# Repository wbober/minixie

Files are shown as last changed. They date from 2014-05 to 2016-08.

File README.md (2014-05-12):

minixie
=======
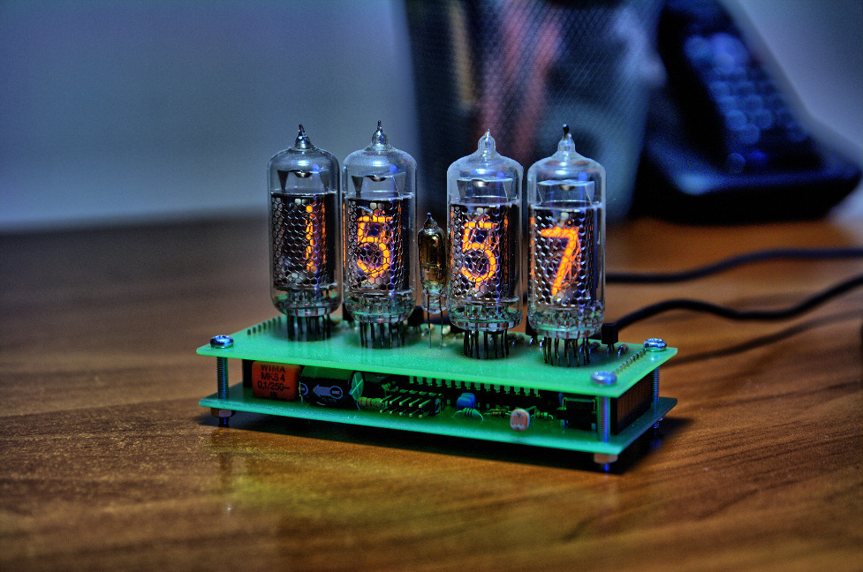
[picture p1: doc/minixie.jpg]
minixie


This project is my take on creating a simple Nixie tube clock. The design uses few
components but packs some nice features.

Features
--------
* a real time clock with super cap backup
* a buzzer
* a light intensity sensor
* an auxiliary connector (UART, IRQ, GPIO, +5V)
* support for an optional DCF77 decoder

Hardware
--------
* only 3 ICs (7805, ATMega8, and 74141 driver)
* single side PCBs
* through-hole components
* designed for LC531 tubes
* small size (46x108mm)
* EagleCAD source for schematics and PCB

Software
--------
* written in C
* tested with AVRStudio/Eclipse

License
-------
Copyright (c) 2012-2014 Wojciech Bober
Licensed under the GNU GPL v2 license

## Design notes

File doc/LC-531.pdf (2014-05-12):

www.tube-tester.com

File created by Dieter Waechter

# Dieter’s Nixie Tube Data Archive

This file is a part of Dieter's Nixie- and display tubes data archive

If you have more datasheets, articles, books, pictures or other information about Nixie tubes or other display devices please let me know. Thank you!

Document in this file | Unitra-Dolam – LC-531 – original datasheet
Display devices in this document | LC-531

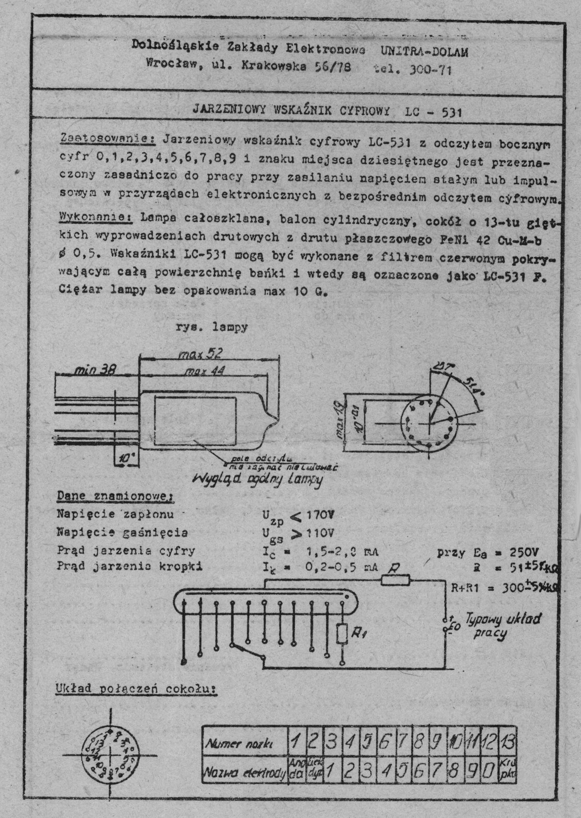
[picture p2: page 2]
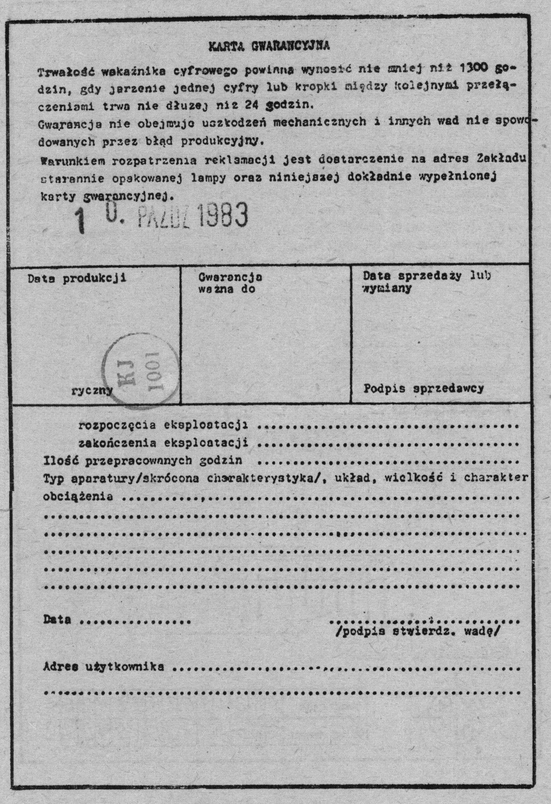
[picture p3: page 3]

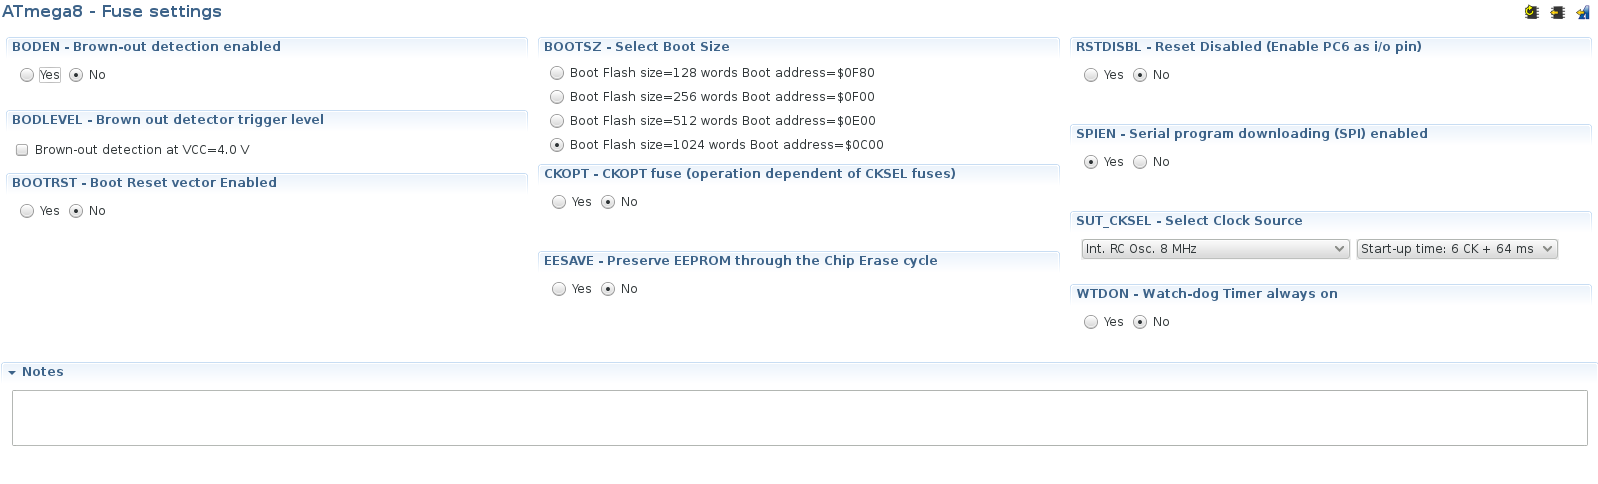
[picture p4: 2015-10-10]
bin/fuses.png

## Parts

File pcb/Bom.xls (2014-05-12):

Qty | Value | Device | Parts
1 |  | MA05-2 | ISP
1 |  | MA06-1 | SV3
1 |  | MA07-1 | SV2
1 |  | MA10-1 | SV1
1 |  | PINHD-1X2 | JP1
1 |  | PINHD-1X3 | JP2
1 | 0.1F | CPOL-EUE5-13 | C9 | 1
1 | 0.47uF/250V | C10/6 | C11 | 1
1 | 1k | R-EU_0204/5 | R7
1 | 1N4148DO35-7 | 1N4148DO35-7 | D3 | 1
1 | 4,7uF/250V | CPOL-EUTT5D10 | C12 | 1
1 | 4k7 | R-EU_0204/5 | R9 | 1
1 | 10k | R-EU_0204/7 | R5 | 1
1 | 10mH | L-US0207/10 | L1, L3 | 2
1 | 10uF/16V | CPOL-EUE2.5-6 | C17 | 1
1 | 47uF/16V | CPOL-EUE2.5-7 | C14 | 1
1 | 32kHz | XTAL | Q1 | 1
1 | 100k | R-EU_0204/5 | R2 | 1
12 | 100nF | C-EU025-025X050 | C1, C2, C3, C4, C5, C6, C7, C8, C10, C13, C16, C19 | 12
2 | 270k | R-EU_0204/5 | R1,R6 | 2
1 | 2200uH | L-US6000-XXX-RC | L4 | 1
1 | 7805L | 7805L | IC3 | 1
1 | 74141N | 74141N | IC4 | 1
1 | DCJ0202 | DCJ0202 | J1 | 1
1 | IRF740 | IRF740 | Q3 | 1
1 | KSS1201 | KSS1201 | SP1 | 1
1 | MEGA8-P | MEGA8-P | IC1 | 1
1 | UF4003 | UF4003 | D1 | 1

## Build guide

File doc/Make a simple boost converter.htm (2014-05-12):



DC/DC Boost calc DIY boost converter calculator!

- Home (http://www.ladyada.net)
- About (http://www.ladyada.net/about.html)
  - ladyada.net (http://www.ladyada.net/about.html)
  - Portfolio (http://www.ladyada.net/portfolio/2007/index.html)
  - Research (http://www.ladyada.net/pub/research.html)
  - Press (http://www.ladyada.net/pub/press.html)
  - Publication & Presentation (http://www.ladyada.net/pub/pub.html)
  - Photos (http://www.flickr.com/photos/ladyada/)
  - Wiki (backend) (http://www.ladyada.net/wiki)
- Projects (http://www.ladyada.net/make/)
  - Arduino »
    - Datalogger Shield (http://www.ladyada.net/make/logshield/)
    - Ethernet Shield (http://www.ladyada.net/make/eshield/)
    - GPS Shield (http://www.ladyada.net/make/gpsshield/)
    - Proto Shield (http://www.ladyada.net/make/pshield/)
    - Motor Shield (http://www.ladyada.net/make/mshield/)
    - Wave Shield (http://www.ladyada.net/make/waveshield/)
  - Adj. power supply (http://www.ladyada.net/make/bbpsup/)
  - Brain Machine (http://www.ladyada.net/make/brain/)
  - BoArduino (http://www.ladyada.net/make/boarduino/)
  - DIGG Button (http://www.ladyada.net/make/digg/)
  - Drawdio (http://www.ladyada.net/make/drawdio/)
  - Fuzebox (http://www.ladyada.net/make/fuzebox/)
  - Game Grrl (http://www.ladyada.net/make/gamegrrl/)
  - Game of Life (http://www.ladyada.net/make/conway/)
  - Ice Tube clock (http://www.ladyada.net/make/icetube/)
  - MIDIsense (http://www.ladyada.net/make/midisense/)
  - MiniPOV2 (http://www.ladyada.net/make/minipov2/)
  - MiniPOV3 (http://www.ladyada.net/make/minipov3/)
  - MintyMP3 (http://www.ladyada.net/make/minty/)
  - MintyBoost (http://www.ladyada.net/make/mintyboost/)
  - MONOCHRON (http://www.ladyada.net/make/monochron/)
  - SIM Reader (http://www.ladyada.net/make/simreader/)
  - SpokePOV (http://www.ladyada.net/make/spokepov/)
  - TV-B-Gone (http://www.ladyada.net/make/tvbgone/)
  - Tweet-a-Watt (http://www.ladyada.net/make/tweetawatt/)
  - USBtinyISP (http://www.ladyada.net/make/usbtinyisp/)
  - Wave Bubble (http://www.ladyada.net/make/wavebubble/)
  - x0xb0x (http://www.ladyada.net/make/x0xb0x/)
  - XBee (http://www.ladyada.net/make/xbee/)
  - YBox2 (http://www.ladyada.net/make/ybox2/)
  - Quickies »
    - USB Gamepad (http://www.ladyada.net/make/usbgamepad/index.html)
    - Halloween Pumpkin (http://www.ladyada.net/make/pumpkin/pumpkin.html)
    - Vintage Bike Lite (http://www.ladyada.net/make/vintagelight/index.html)
    - Kite Arial Photo (http://www.ladyada.net/make/sudc4kap/index.html)
    - Bike Stand (http://www.ladyada.net/make/bikestand/index.html)
    - LiIon Bike Lite (http://www.ladyada.net/make/bikelite/index.html)
    - Pogo Jib (http://www.ladyada.net/make/pogojig/index.html)
    - Mass Programming (http://www.ladyada.net/make/massprog/index.html)
    - Solar LiPo Charging (http://www.ladyada.net/make/solarlipo/index.html)
    - Magstripe Reader (http://www.ladyada.net/make/magstripe/index.html)
    - Solar Tracker (http://www.ladyada.net/make/solarlogger/index.html)
    - TRON Bag (http://www.ladyada.net/make/tronbag/)
  - More... (http://www.ladyada.net/make/)
  - ->Instructables (http://www.instructables.com/member/ladyada/)
- Learn (http://www.ladyada.net/learn/)
  - Arduino tutorial (http://www.ladyada.net/learn/arduino/)
  - AVR tutorial (http://www.ladyada.net/learn/avr/)
  - Barcode scanners (http://www.ladyada.net/learn/barcodescan/)
  - EL Wire tutorial (http://www.ladyada.net/learn/el-wire/)
  - LCDs (http://www.ladyada.net/learn/lcd/)
  - LEDs (http://www.ladyada.net/learn/arduino/LEDs.html)
  - Multimeter tutorial (http://www.ladyada.net/learn/multimeter/)
  - Digital scales (http://www.ladyada.net/learn/scale/)
  - Sensors » (http://www.ladyada.net/learn/sensors/)
    - FSR (http://www.ladyada.net/learn/sensors/fsr.html)
    - CdS Photocell (http://www.ladyada.net/learn/sensors/cds.html)
    - Temperature (http://www.ladyada.net/learn/sensors/tmp36.html)
    - Tilt (http://www.ladyada.net/learn/sensors/tilt.html)
    - PIR (http://www.ladyada.net/learn/sensors/pir.html)
    - Thermocouple (http://www.ladyada.net/learn/sensors/thermocouple.html)
    - IR Receiver (http://www.ladyada.net/learn/sensors/ir.html)
  - Breakout boards » (http://www.ladyada.net/learn/breakoutplus/)
    - DS1307 RTC (http://www.ladyada.net/learn/breakoutplus/ds1307rtc.html)
    - MAX6675 (http://www.ladyada.net/learn/sensors/thermocouple.html)
    - ATmega32u4 Breakout+ (http://www.ladyada.net/learn/products/atmega32u4breakout/)
  - Products » (http://www.ladyada.net/products/)
    - i2c/SPI LCD backpack (http://www.ladyada.net/learn/products/i2cspilcdbackpack/)
    - USB Boarduino (http://www.ladyada.net/learn/products/usbboarduino/)
    - ATmega32u4 Breakout+ (http://www.ladyada.net/learn/products/atmega32u4breakout/)
    - 2.8 TFT touchscreen (http://www.ladyada.net/learn/products/tfttouchbreakout/)
    - 1.8 SPI TFT (http://www.ladyada.net/learn/products/18tftbreakout/)
    - RFID/NFC (http://www.ladyada.net/learn/products/rfidnfc/)
  - Chumby Hacker Board (http://www.ladyada.net/learn/chumby/)
  - Soldering tutorial (http://www.ladyada.net/learn/soldering/)
  - Power Supply tutorial (http://www.ladyada.net/learn/powersupply/)
  - Brother KH-9033 tutorial (http://www.ladyada.net/learn/electroknit/)
  - USB reverse-engineering tutorial (http://www.ladyada.net/learn/diykinect/)
  - Calipers tutorial (http://www.ladyada.net/learn/calipers/)
  - RGB LED Strips (http://www.ladyada.net/products/rgbledstrip/)
  - RGB LED Pixels (http://www.ladyada.net/products/rgbledpixels/)
  - LiIon & LiPoly Batteries (http://www.ladyada.net/learn/lipoly/)
- Library (http://www.ladyada.net/library/)
  - Arduino Hacks (http://www.ladyada.net/library/arduino/)
  - Batteries (http://www.ladyada.net/library/batteries.html)
  - Boost Calc (http://www.ladyada.net/library/diyboostcalc.html)
  - E.E. Tools (http://www.ladyada.net/library/equipt/)
  - E.E. Computer (http://www.ladyada.net/library/hackcomputer.html)
  - Find Parts (http://www.ladyada.net/library/procure/)
  - Kits (http://www.ladyada.net/library/kits/)
  - Laser (http://www.ladyada.net/library/laser/)
  - uC Annoyances (http://www.ladyada.net/library/ucannoyances.html)
  - Open Source Hardware (http://www.ladyada.net/library/openhardware/)
  - PCB Design & Tips (http://www.ladyada.net/library/pcb/)
  - PIC vs. AVR (http://www.ladyada.net/library/picvsavr.html)
  - Software (http://www.ladyada.net/library/software/index.html)
  - SMT (http://www.ladyada.net/library/smt/index.html)
  - Zen-Cart Mods (http://www.ladyada.net/library/zencart/)
- Blog (http://www.adafruit.com/blog/)
- Store (http://www.adafruit.com)
- Forums (http://forums.adafruit.com/)

ladyada.net

boostboost!

For many small projects, its cheaper and easier to DIY a boost converter than to buy a specialty chip. DIY converters are usually not as efficient but they're quick & cheap!



The above schematic section shows how I designed a 30-60V vacuum fluorescent tube display driven from a microcontroller pin.

Tubes such as VFDs, Nixies, Decatrons, etc require high voltage to light the gas in the tube. In order to reduce cost, we use a microconrtoller to make a boost converter and avoid paying $5 for a seperate chip. We can do this because we don't need a precision output and the current draw is mostly constant. The boost regulator is run open-loop there is no feedback resistor divider as it isn't necessary as long as the input voltage is within a reasonable range

The microcontroller runs at 8MHz so the 8-bit PWM output is 31250 Hz. The inductor and output capacitor is calculated below. The diode is a standard Schottkey type, but make sure you specify one that can handle the full voltage difference and peak current. The switch just has to be able to handle the max voltage plus some for safety. Note that this design is meant for 'static' output currents, not for variable current draw designs. There is no feedback and its very approximate! This is not for precision electronics!

The boost circuit works by connecting the power inductor L1 to ground that current can flow through it by turning on Q2. After a little bit of time, we disconnect the from ground (by turning off Q2) this means that there is no longer a path for the current in L1 to flow to ground. When this happens, the voltage across the inductor increases (this is the electric property of inductors) and charges up C6 . When the voltage increases to the level we want it to be (30V+) we turn on Q2 again which allows the current in L1 to flow back to ground. If we do this fast enough, and C6 large enough, the voltage on C6 is smoothed out and we get a nice steady high voltage

The timing of turning off/on Q2 allows us to modify the output voltage. Normally there is a feedback resistor to the microcontroller but it is not here because we are running it open-loop. To drive Q2 we use the PWM output from the microcontroller and adjust the duty cycle to vary brightness.

These sorts of designs can be easily made with a 555, once you have the PWM output, connect it up to Q2!

For this simple calculator, enter in the freqency, voltage ranges and current ranges and the duty cycle, inductor and current requirements will be displayed!

The calculator

Frequency | Hz | This is the boost converter frequency. For microcontrollers its often the CPU clock / 256
Min Vin | V | The lowest expected input voltage
Max Vin | V | The highest expected input voltage
Min Vout | V | The lowest desired output voltage
Max Vout | V | The highest desired output voltage
Iout | Amps | Output current draw
Vripple | V | Maximum allowable voltage ripple

Min. Duty Cycle | Dmin = 1 - (Vimax/Vomin) | %
Max. duty cycle | Dmax = 1 - (Vimin/Vomax) | %
Min. Inductor size | L > D * Vin * (1-D) / (freq * 2 * Iout ) | uH
Peak inductor current | Ipk = (Vinmax * D)/(f * L) | A
Minimum capacitor | Cap > Iout / (Vripple * freq) | uF
Minimum Schottky diode | Vbreakdown >= Voutmax & Idiode >=Ipk | V A

Don't forget that Duty cycle is the amount of time the switch is off / output is low. Be sure to measure the output voltages before connecting up anything important!

We like the J&W Miller / Bourns RLB9012 inductors and other thru-hole from the same company

Thanks to Riad for some of the math! (http://web.jfet.org/inGrid/)

May 17, 2011 20:07

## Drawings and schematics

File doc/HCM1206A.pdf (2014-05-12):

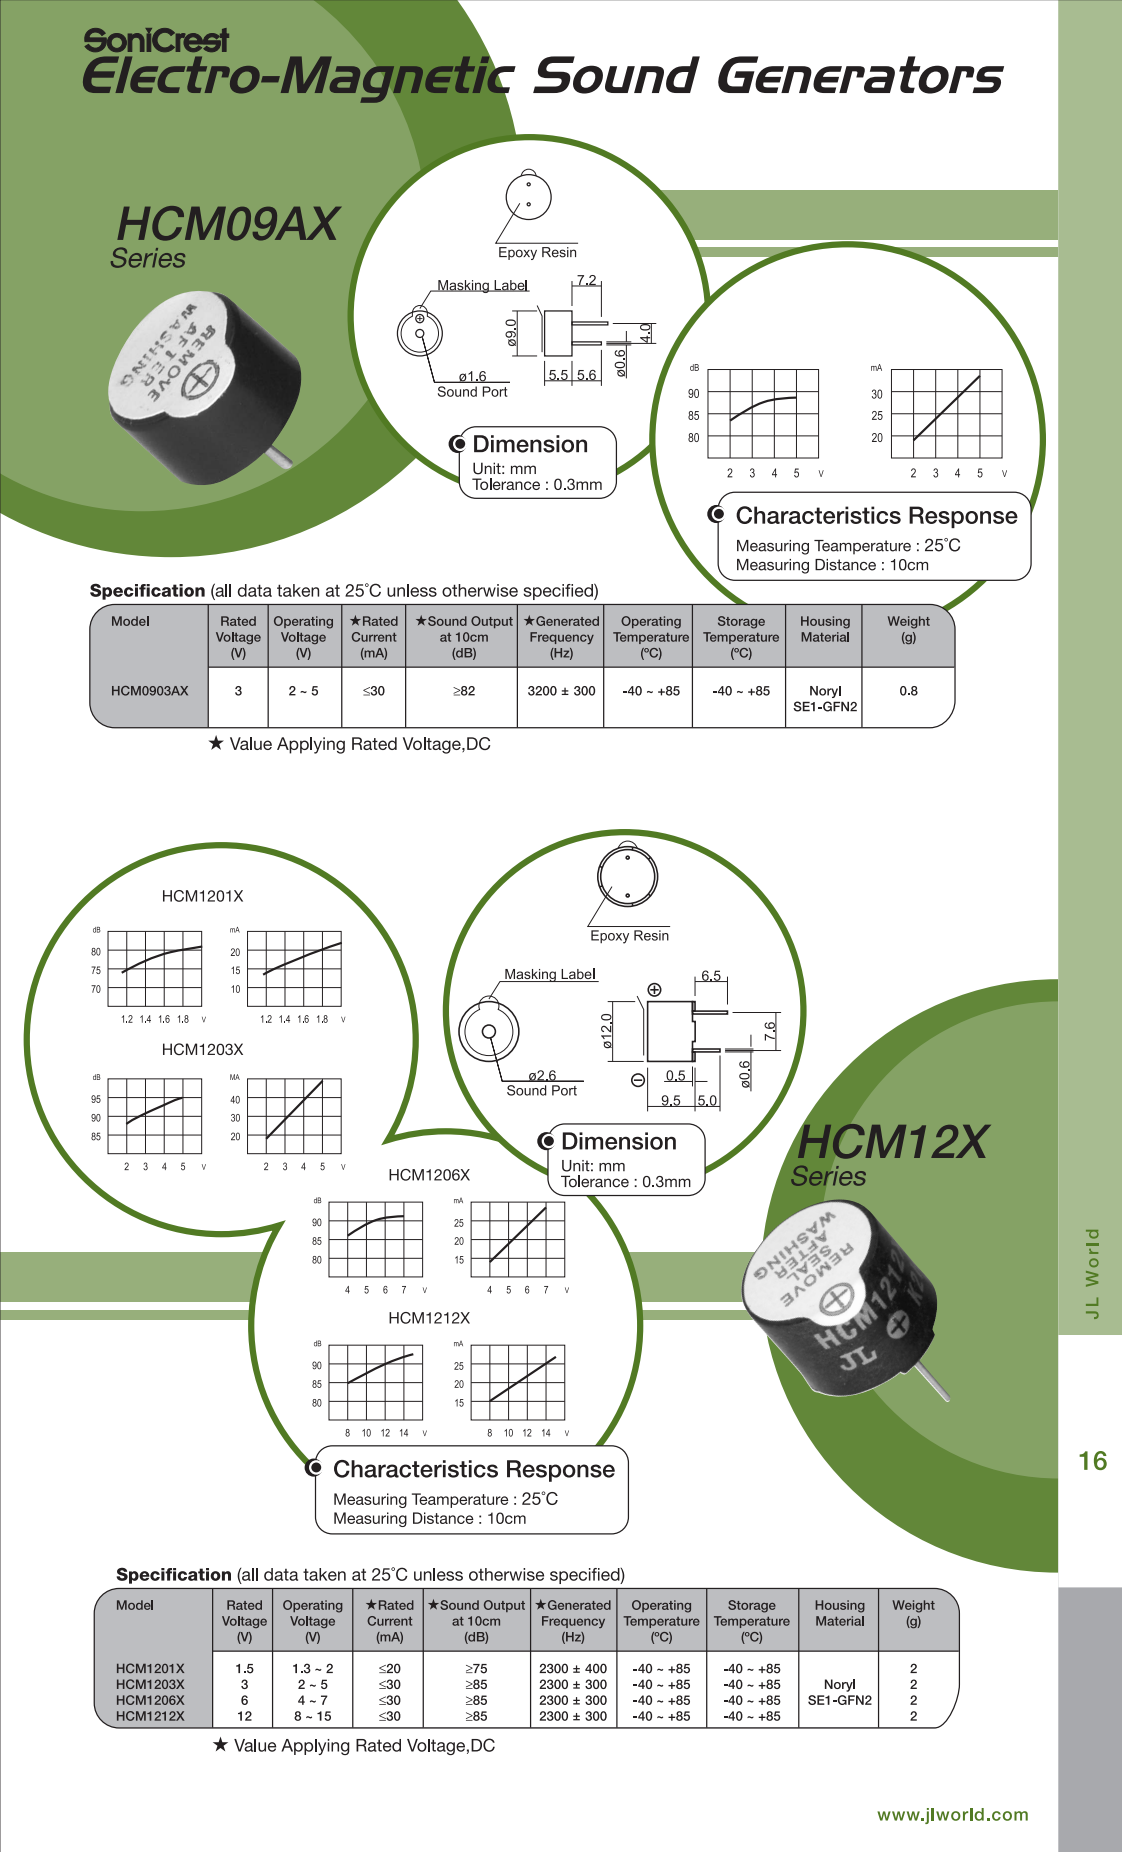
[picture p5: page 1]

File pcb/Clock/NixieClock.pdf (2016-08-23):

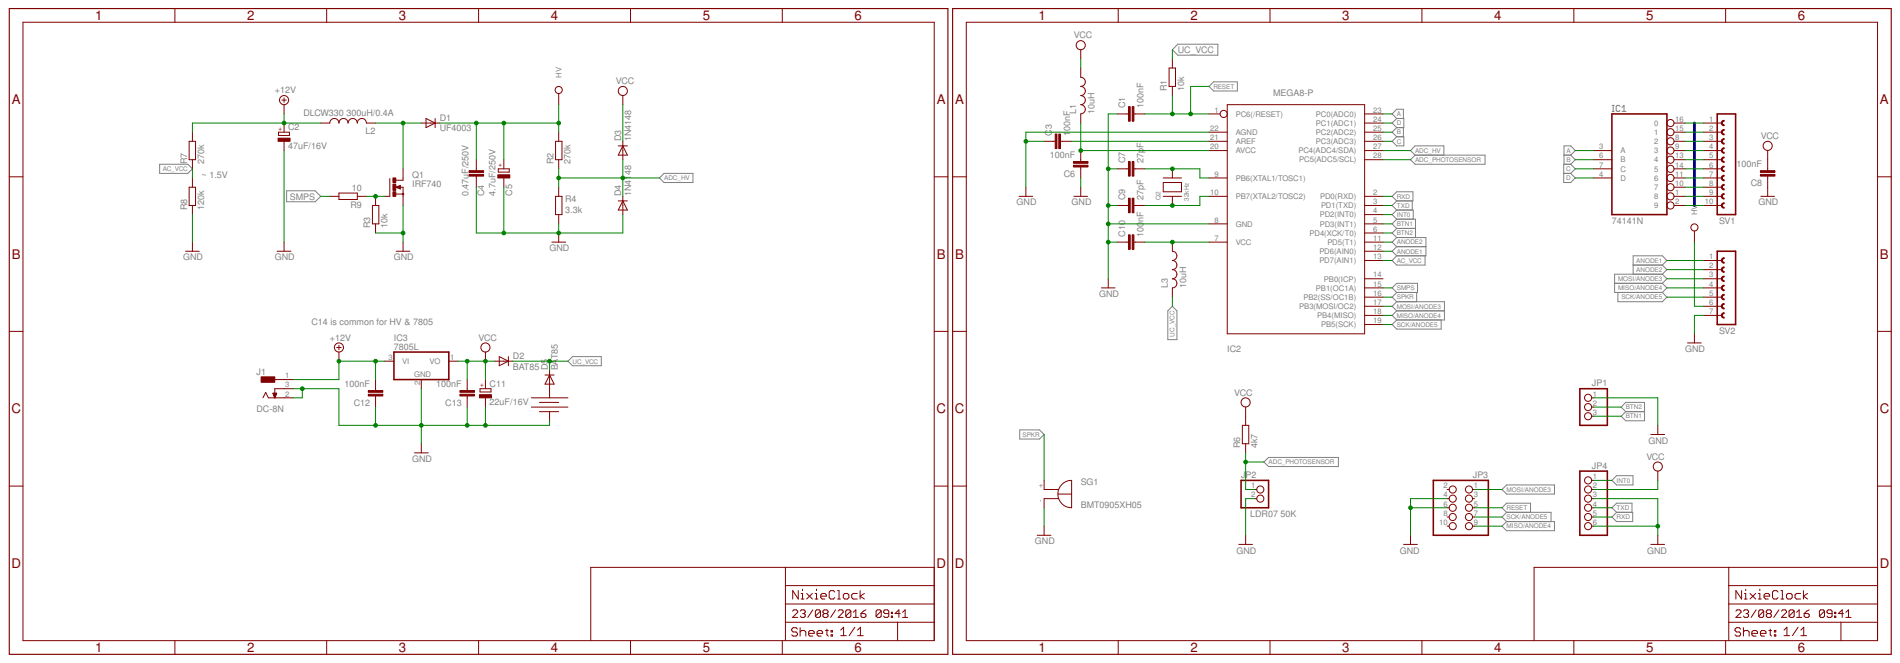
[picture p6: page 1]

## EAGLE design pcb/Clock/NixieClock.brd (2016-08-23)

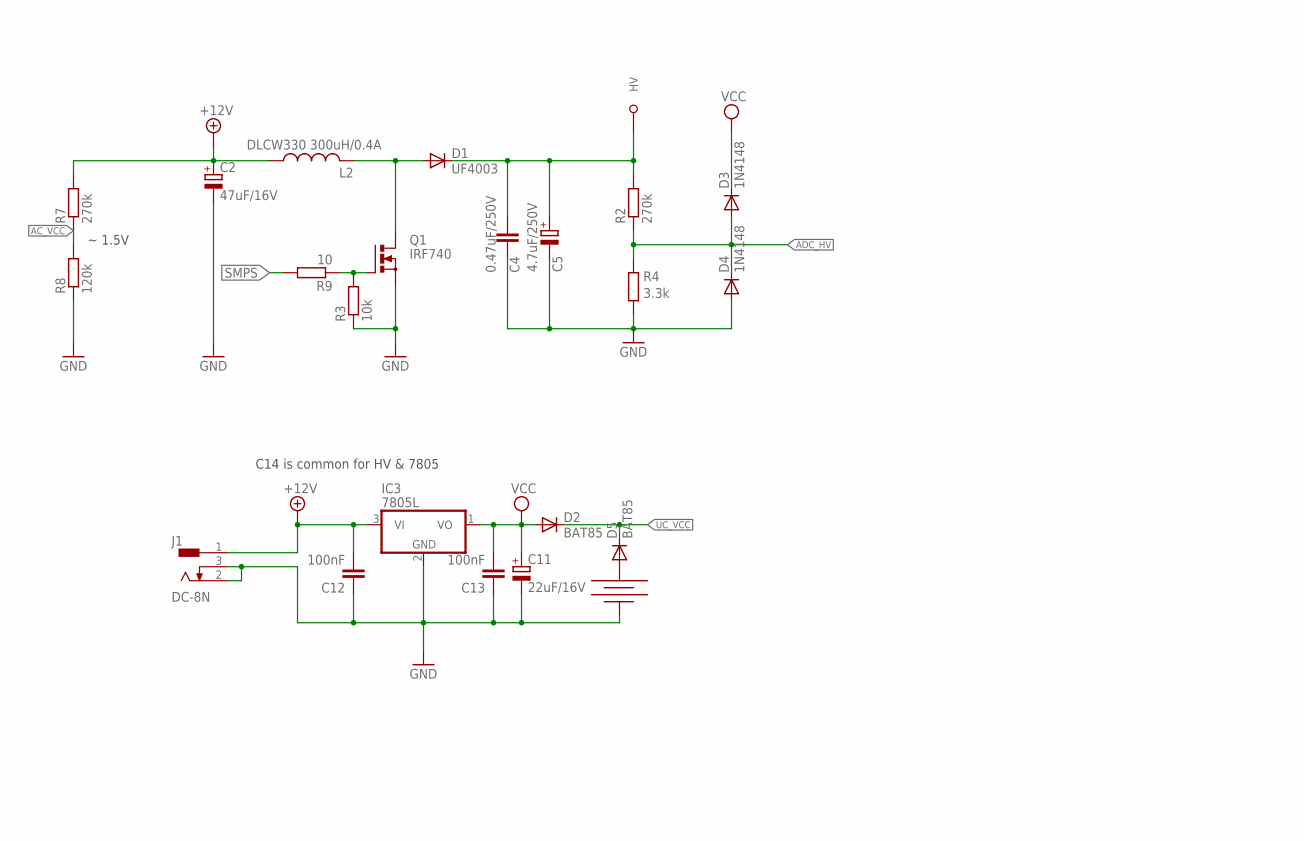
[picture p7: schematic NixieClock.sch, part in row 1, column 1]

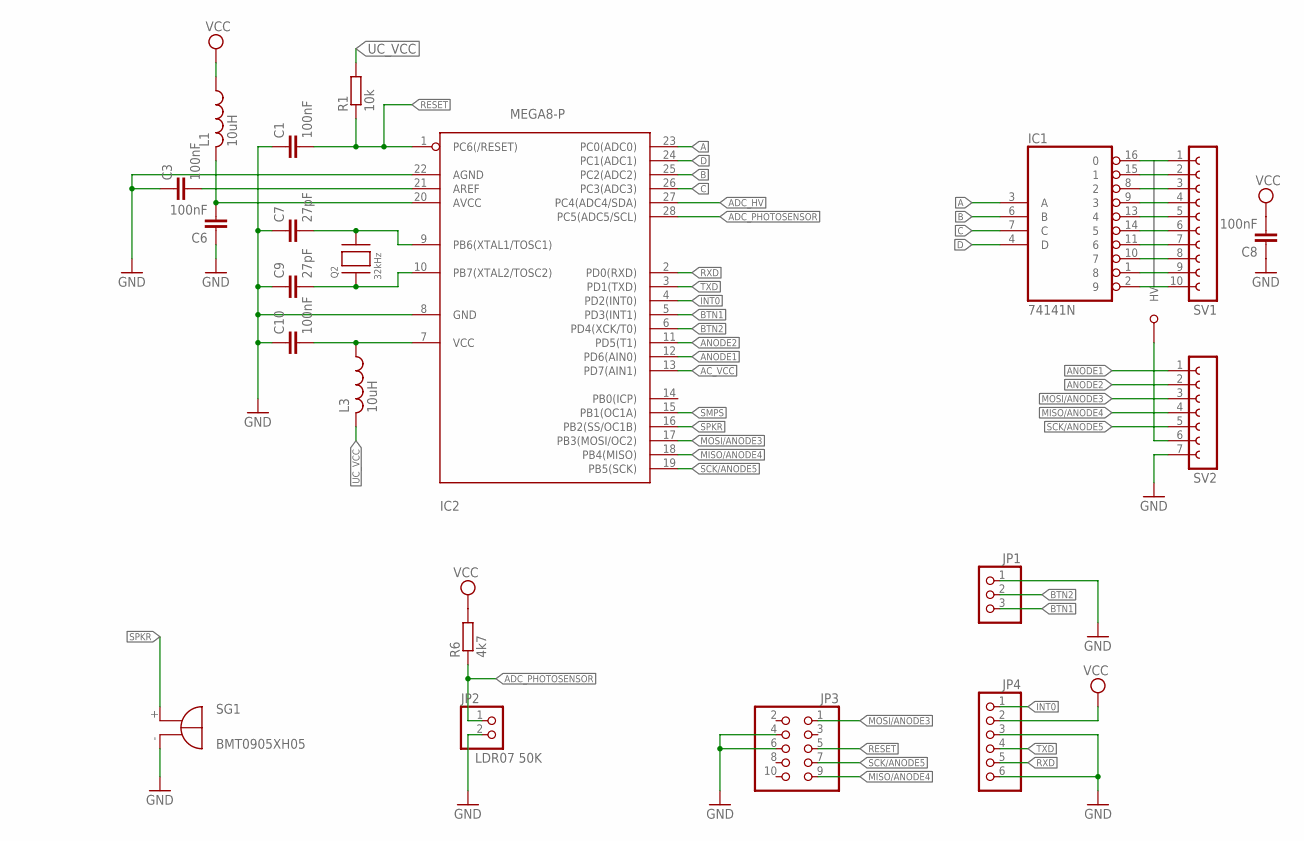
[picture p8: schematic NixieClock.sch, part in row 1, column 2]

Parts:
C1, C3, C6, C10, C12, C13: 100nF; C025-025X050
C2: 47uF/16V; E2,5-7
C4: 0.47uF/250V; C10B6
C5: 4.7uF/250V; CAP_RADIAL
C7, C9: 27pF; C025-025X050
C8: 100nF; C050-025X075
C11: 22uF/16V; E2,5-6
D1: UF4003; DO41-10
D2, D5: BAT85; DO35-7
D3, D4: 1N4148; DO35-7
IC1: 74141N; DIL16
IC2: MEGA8-P; DIL28-3
IC3: 7805L; TO92
J1: DC-8N
JP1: PINHD-1X3/90; 1X03/90
JP2: LDR07 50K; 1X02
JP3: PINHD-2X5/90; 2X05/90
JP4: PINHD-1X6/90; 1X06/90
L1: 10uH; 0204/7
L2: DLCW330 300uH/0.4A; MURATA-CHOKE-7-4
L3: 10uH; 0204/5
Q1: IRF740; TO220BH
Q2: 32kHz; QS
R1: 10k; 0207/12
R2, R7: 270k; 0204/5
R3: 10k; 0204/5
R4: 3.3k; 0204/5
R6: 4k7; 0204/5
R8: 120k; 0204/5
R9: 10; 0204/5
SG1: BMT0905XH05
SV1: FE10-1; FE10
SV2: FE07-1; FE07
U$3: BAT1220THT; 1220

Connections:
+12V: C2.+, C12.2, IC3.3 (VI), J1.1, L2.P$1 (1), R7.2
A: IC1.3 (A), IC2.23 (PC0(ADC0))
AC_VCC: IC2.13 (PD7(AIN1)), R7.1, R8.2
ADC_HV: D3.A, D4.C, IC2.27 (PC4(ADC4/SDA)), R2.1, R4.2
ADC_PHOTOSENSOR: IC2.28 (PC5(ADC5/SCL)), JP2.1, R6.1
ANODE1: IC2.12 (PD6(AIN0)), SV2.1
ANODE2: IC2.11 (PD5(T1)), SV2.2
B: IC1.6 (B), IC2.25 (PC2(ADC2))
BTN1: IC2.5 (PD3(INT1)), JP1.3
BTN2: IC2.6 (PD4(XCK/T0)), JP1.2
C: IC1.7 (C), IC2.26 (PC3(ADC3))
D: IC1.4 (D), IC2.24 (PC1(ADC1))
D1: IC1.2 (9), SV1.1
D2: IC1.1 (8), SV1.2
D3: IC1.16 (0), SV1.3
D4: IC1.15 (1), SV1.4
D5: IC1.14 (5), SV1.5
D6: IC1.13 (4), SV1.6
D7: IC1.11 (6), SV1.7
D8: IC1.10 (7), SV1.8
D9: IC1.9 (3), SV1.9
D10: IC1.8 (2), SV1.10
GND: C1.1, C2.-, C3.1, C4.2, C5.P$4 (-), C6.1, C7.1, C8.1, C9.1, C10.1, C11.-, C12.1, C13.1, D4.A, IC1.12 (GND), IC2.8 (GND), IC2.22 (AGND), IC3.2 (GND), J1.2, J1.3, JP1.1, JP2.2, JP3.4, JP3.6, JP4.3, JP4.6, Q1.S, R3.1, R4.1, R8.1, SG1.-, SV2.7, U$3.-
HV: C4.1, C5.P$3 (+), D1.C, R2.2, SV2.6
INT0: IC2.4 (PD2(INT0)), JP4.1
MISO/ANODE4: IC2.18 (PB4(MISO)), JP3.9, SV2.4
MOSI/ANODE3: IC2.17 (PB3(MOSI/OC2)), JP3.1, SV2.3
unnamed: C7.2, IC2.9 (PB6(XTAL1/TOSC1)), Q2.P$2
unnamed: C9.2, IC2.10 (PB7(XTAL2/TOSC2)), Q2.P$1
unnamed: D5.A, U$3.+
unnamed: Q1.G, R3.2, R9.1
unnamed: C6.2, IC2.20 (AVCC), L1.2
unnamed: C10.2, IC2.7 (VCC), L3.1
unnamed: C3.2, IC2.21 (AREF)
unnamed: D1.A, L2.P$2 (2), Q1.D
RESET: C1.2, IC2.1 (PC6(/RESET)), JP3.5, R1.1
RXD: IC2.2 (PD0(RXD)), JP4.5
SCK/ANODE5: IC2.19 (PB5(SCK)), JP3.7, SV2.5
SMPS: IC2.15 (PB1(OC1A)), R9.2
SPKR: IC2.16 (PB2(SS/OC1B)), SG1.+
TXD: IC2.3 (PD1(TXD)), JP4.4
UC_VCC: D2.C, D5.C, L3.2, R1.2
VCC: C8.2, C11.+, C13.2, D2.A, D3.C, IC1.5 (VCC), IC3.1 (VO), JP4.2, L1.1, R6.2

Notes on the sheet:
C14 is common for HV & 7805
~ 1.5V

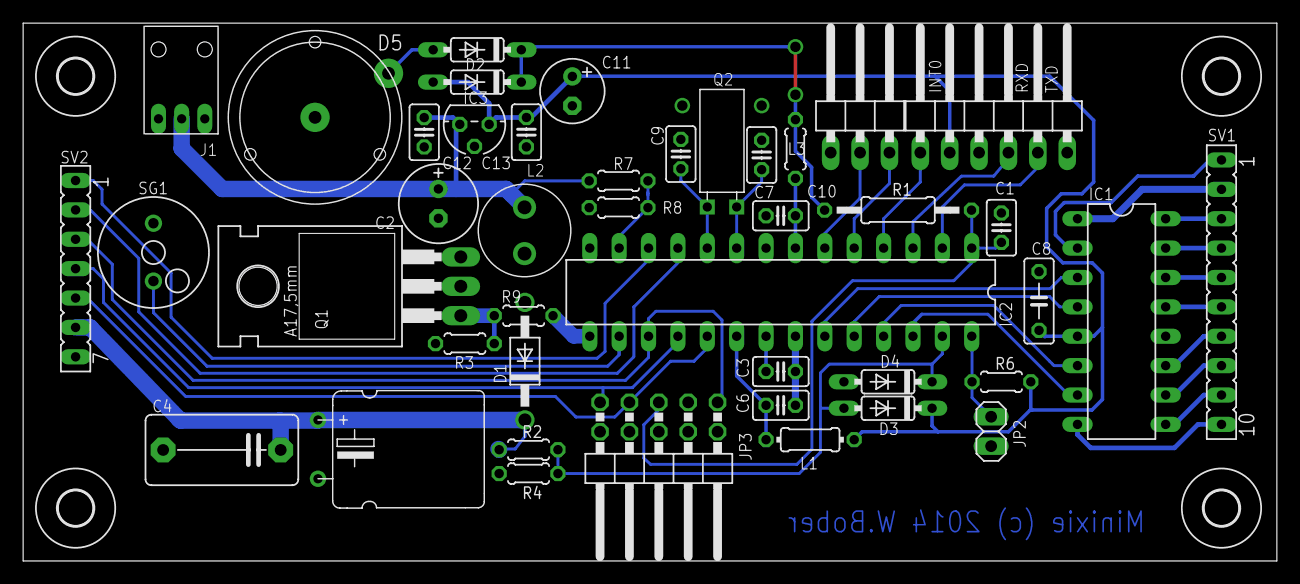
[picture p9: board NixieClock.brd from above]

Board: 2 copper layers, 108.4 x 46.5 mm, 47 parts (0 on the bottom side), 43 nets.

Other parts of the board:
U$5, U$6, U$7, U$8: 3,0

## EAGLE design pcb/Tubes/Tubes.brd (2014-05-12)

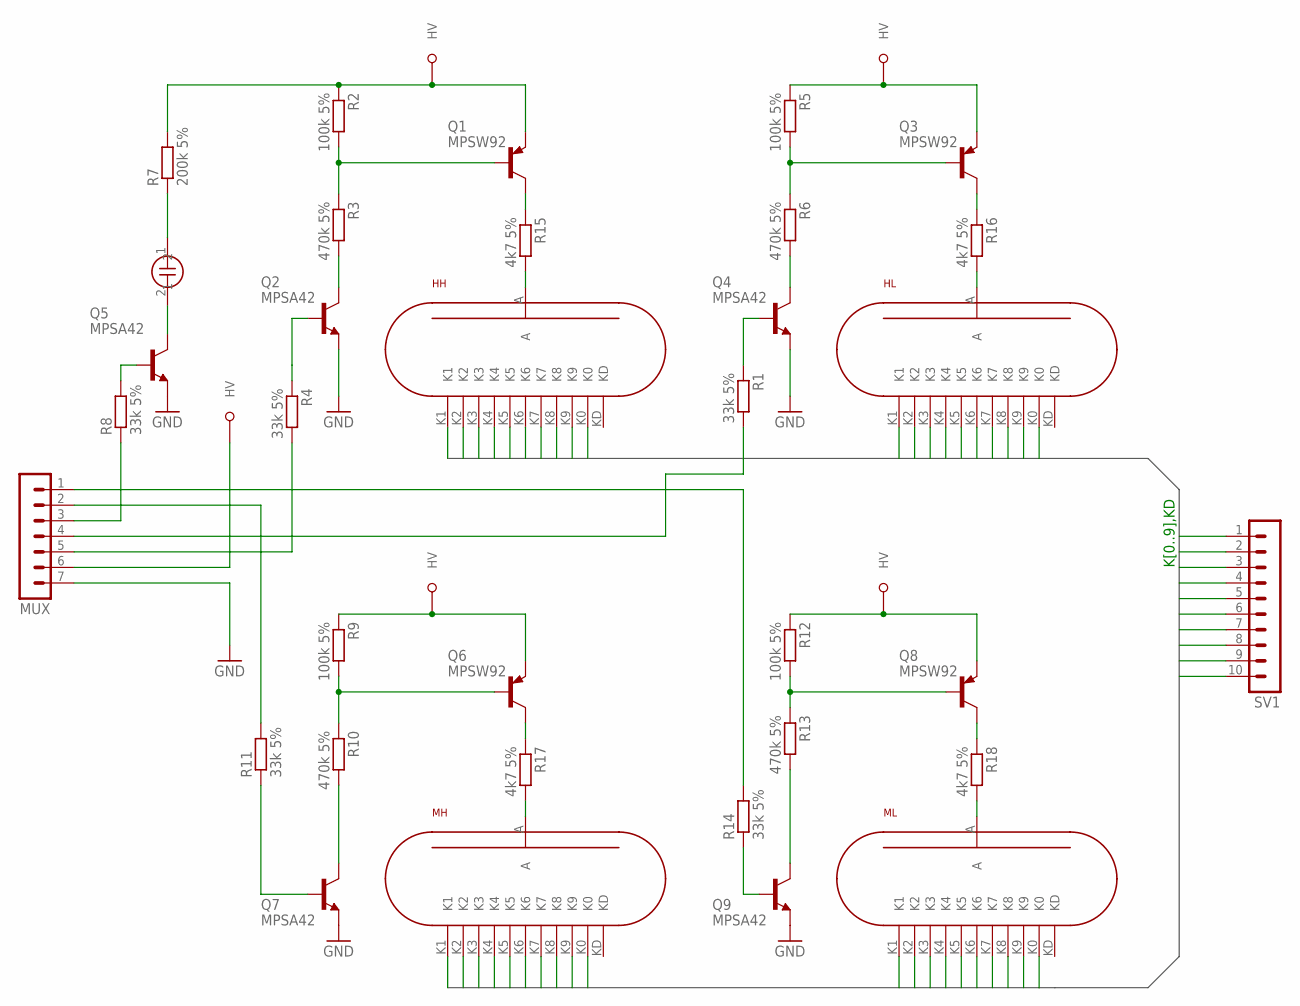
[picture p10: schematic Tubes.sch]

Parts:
HH: LC531
HL: LC531
MH: LC531
ML: LC531
MUX: MA07-1
NEON: NEON
Q1, Q3, Q6, Q8: MPSW92; TO92-CBE
Q2, Q4, Q5, Q7, Q9: MPSA42; TO92-CBE
R1, R4, R8, R11, R14: 33k 5%; 0204/5
R2, R5, R9, R12: 100k 5%; 0204/5
R3, R6, R10, R13: 470k 5%; 0204/5
R7: 200k 5%; 0204/5
R15, R16, R17, R18: 4k7 5%; 0204/5
SV1: MA10-1

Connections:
DOT: MUX.3, R8.1
GND: MUX.7, Q2.E, Q4.E, Q5.E, Q7.E, Q9.E
HH: MUX.5, R4.2
HL: MUX.4, R1.2
HV: MUX.6, Q1.E, Q3.E, Q6.E, Q8.E, R2.1, R5.1, R7.2, R9.1, R12.1
K0: HH.K0, HL.K0, MH.K0, ML.K0, SV1.3
K1: HH.K1, HL.K1, MH.K1, ML.K1, SV1.1
K2: HH.K2, HL.K2, MH.K2, ML.K2, SV1.2
K3: HH.K3, HL.K3, MH.K3, ML.K3, SV1.4
K4: HH.K4, HL.K4, MH.K4, ML.K4, SV1.6
K5: HH.K5, HL.K5, MH.K5, ML.K5, SV1.8
K6: HH.K6, HL.K6, MH.K6, ML.K6, SV1.10
K7: HH.K7, HL.K7, MH.K7, ML.K7, SV1.9
K8: HH.K8, HL.K8, MH.K8, ML.K8, SV1.7
K9: HH.K9, HL.K9, MH.K9, ML.K9, SV1.5
MH: MUX.2, R11.2
ML: MUX.1, R14.2
unnamed: MH.A, R17.2
unnamed: ML.A, R18.2
unnamed: HH.A, R15.2
unnamed: HL.A, R16.2
unnamed: Q1.C, R15.1
unnamed: Q3.C, R16.1
unnamed: Q6.C, R17.1
unnamed: Q8.C, R18.1
unnamed: NEON.1, R7.1
unnamed: Q2.B, R4.1
unnamed: Q4.B, R1.1
unnamed: Q7.B, R11.1
unnamed: Q9.B, R14.1
unnamed: Q2.C, R3.2
unnamed: Q7.C, R10.2
unnamed: Q9.C, R13.2
unnamed: Q4.C, R6.2
unnamed: NEON.2, Q5.C
unnamed: Q1.B, R2.2, R3.1
unnamed: Q3.B, R5.2, R6.1
unnamed: Q6.B, R9.2, R10.1
unnamed: Q8.B, R12.2, R13.1
S$1: Q5.B, R8.2

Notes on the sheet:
K[0..9],KD

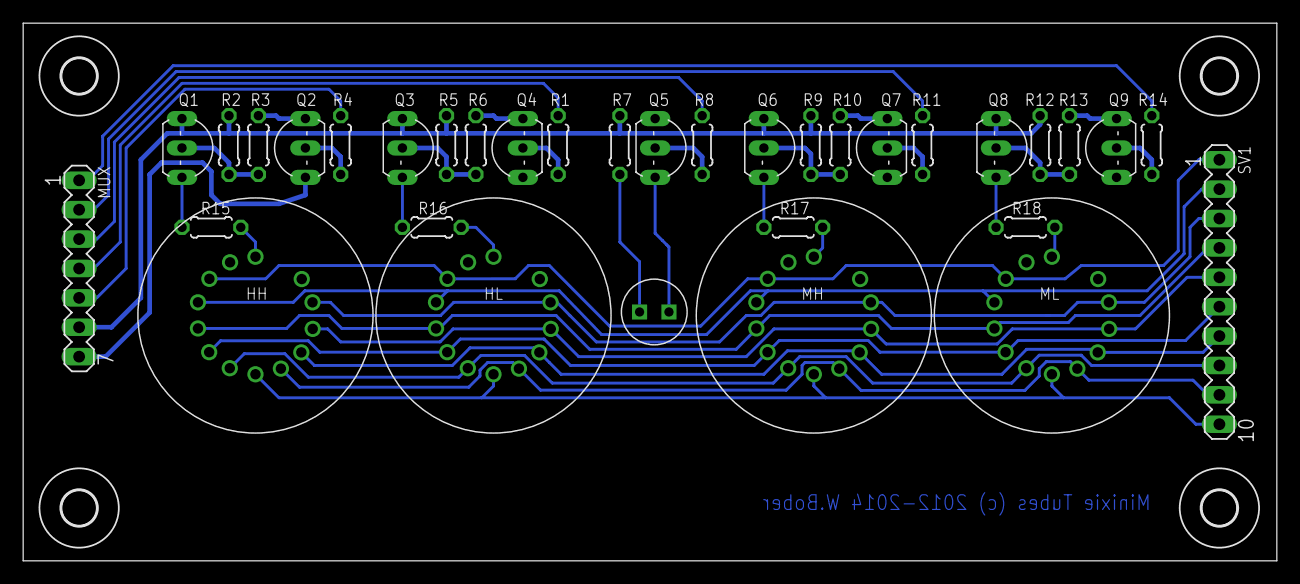
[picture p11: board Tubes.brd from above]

Board: 2 copper layers, 108.4 x 46.5 mm, 38 parts (0 on the bottom side), 40 nets.

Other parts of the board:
E$1, E$2, E$3, E$4: 3,0

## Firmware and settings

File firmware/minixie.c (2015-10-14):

/**
 * Minixie - a simple nixie tube clock.
 * Copyright (C) 2012-2014, Wojciech Bober
 *
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
 */
#include <stdlib.h>
#include <inttypes.h>
#include <avr/io.h>
#include <avr/interrupt.h>
#include <avr/sleep.h>
#include <avr/wdt.h>
#include <util/delay.h>
#include "logger.h"
#include "dcf77.h"
#include "minixie.h"
#include "uart.h"
#include "adc.h"

uint16_t timer = 0;

/* 
 * Anode mapping table:
 * HH -> PB5
 * HL -> PB4
 * MH -> PD5
 * ML -> PD6
 * DOT -> PB3
 */
static const pad_t const anode_pad_map[] = {
	PAD(&PORTB, 5),
	PAD(&PORTB, 4),
	PAD(&PORTD, 5),
	PAD(&PORTD, 6),
	PAD(&PORTB, 3),
};

static const pad_t const digit_pad_map[] = {
	PAD(&PORTC, 0),
	PAD(&PORTC, 2),
	PAD(&PORTC, 3),
	PAD(&PORTC, 1),
};

static const pad_t buzzer_pad = PAD(&PORTB, 2);

#if ADAPTIVE_DC == 1
static const uint16_t const dc_light_map[][2] = {
	{700,  80},
	{800,  70},
	{900,  60},
	{1000, 50},
};
#endif

typedef void (*pt)(void);

// digit mapping table
static const uint8_t const dt[] = {0,9,8,1,4,7,2,3,6,5};

/**
 * Module context - holds variables related to the module state.
 *
 */
typedef struct  {
	int tick: 1;
	int poll: 1;
	int uart: 1;
	int beep: 1;
	int dot : 1;

	int debug: 1;
	int input: 1;

	int dcf_sync: 1;
	int dcf_irq: 1;
	int dcf_debug: 1;
	int dcf_sync_cnt;

	uint8_t duty_cycle;
	uint8_t dot_pwm;

	uint8_t digit[4];

	uint16_t adc_hv;
	uint16_t adc_light;

	clock_t time;
	clock_t alarm;

} ctx_t;

volatile static ctx_t ctx = {
	.tick = 1,
	.dot = 1,
	.debug = 0,
	.beep = 0,
	.dcf_sync_cnt = 0,
	.duty_cycle = SMPS_PWM_DC,
	.dot_pwm = 0,
	.digit = {0},
	.adc_hv = 0,
	.adc_light = 0,
	.alarm = {255},
};

static void digit_mux(void);
static void rtc_tick(void);
static void dc_toggle(void);

// External interrupt
ISR(INT0_vect)
{
	if (dcf77_handler() > 0) {
		ctx.dcf_sync_cnt++;
		ctx.dcf_sync = 1;
	}
	ctx.dcf_irq = 1;
}

// Mux timer
ISR(TIMER0_OVF_vect)
{
	digit_mux();
}

// SPMS PWM timer
//ISR(TIMER1_COMPA_vect)
//{
//}

// RTC clock timer - IRQ invoked once a second
ISR(TIMER2_OVF_vect)
{
	timer += 256;
	rtc_tick();
}

// Analog comparator
ISR(ANA_COMP_vect)
{
	dc_toggle();
}

static void hw_init(void)
{
	// set the anode pins as an output
	DDRB = _BV(PB2) | _BV(PB3) | _BV(PB4) | _BV(PB5);
	DDRD = _BV(PD5) | _BV(PD6);
	// set the digit pins as an output
	DDRC = _BV(PC0) | _BV(PC1) | _BV(PC2) | _BV(PC3);
	
	// enable pull-ups on button inputs
	PORTD = _BV(PD3) | _BV(PD4);
	
	// Enable IRQ0 on PD2 
	MCUCR |= _BV(ISC00);
	GICR |= _BV(INT0);

	// Tubes' mux timer
	// generate an IRQ on overflow
	TIMSK |= _BV(TOIE0);

	// Fast PWM with ICR1 as TOP
	// with OC1A as output pin (non-inverting)
	// (note: for inverting add _BV(COM1A0))
	TCCR1A = _BV(WGM11) | _BV(COM1A1);
	TCCR1B = _BV(WGM13) | _BV(WGM12);
	DDRB |= _BV(PB1);

	ICR1 = SMPS_PWM_PERIOD;
	OCR1A = (ctx.duty_cycle*SMPS_PWM_PERIOD)/100;

	// RTC timer
	// clock div 128, normal mode
	TCCR2 = _BV(CS22) | _BV(CS20);
	// enable asynchronous operation
	ASSR = _BV(AS2);
	// generate an IRQ on timer overflow
	TIMSK |= _BV(TOIE2);

	// Analog Comparator, rising edge
	ACSR = _BV(ACBG) | _BV(ACIE) | _BV(ACIS1) | _BV(ACIS0);
}

// Tubes' mux handler - invoked at F_CPU/256 ~= 31.250 khz
static inline
void digit_mux(void)
{
	static unsigned pwm_ocr = 0;
	static unsigned pwm_cnt = 0;
	static unsigned mux_cnt = 0;
	static const pad_t *active_anode = anode_pad_map;

	if (pwm_cnt + 1 < pwm_ocr) {
		PAD_HIGH(active_anode);
	} else {
		PAD_LOW(active_anode);
	}

	// this gives 625Hz PWM frequency 
	if (++pwm_cnt == PWM_TOP) {
		pwm_cnt = 0;
	}
	
	// this gives 250Hz anode mulitplexing
	if (mux_cnt++ < 128) {
		return;
	}
	mux_cnt = 0;

	PAD_LOW(active_anode);
	
	if (active_anode < anode_pad_map + 4)
		active_anode += 1;
	else
		active_anode = anode_pad_map;
	
	if (active_anode < anode_pad_map + 4) {
		int digit = ctx.digit[active_anode - anode_pad_map];
		for (int i = 0; i < 4; i++) {
			if (dt[digit] & _BV(i))
				PAD_HIGH(&digit_pad_map[i]);
			else
				PAD_LOW(&digit_pad_map[i]);
		}
		pwm_ocr = PWM_TOP;
	} else {
		if (ctx.dot) {
			ctx.dot_pwm += (ctx.dot_pwm < PWM_TOP*2/3) ? 1 : 0;
		} else  {
			ctx.dot_pwm -= (ctx.dot_pwm > 0) ? 1 : 0;
		}
		pwm_ocr = ctx.dot_pwm;
	}
}

// RTC tick handler
static inline
void rtc_tick(void)
{
	ctx.poll = 1;
	ctx.tick = 1;
	ctx.dot ^= 1;
	
	if (ctx.time.ss < 59) {
		ctx.time.ss++;
		return;
	}
	ctx.time.ss = 0;

	if (ctx.time.mm < 59) {
		ctx.time.mm++;
		return;
	}
	ctx.time.mm = 0;

	if (ctx.time.hh < 23) {
		ctx.time.hh++;
		return;
	}
	ctx.time.hh = 0;
}

/**
 * Function called when ADC conversion is done.
 *
 */
int adc_cb(int channel, uint16_t value)
{
	if (channel == ADC_HV) {
		ctx.adc_hv = value;
		return ADC_VL;
	} else {
		ctx.adc_light = value;
		return ADC_HV;
	}
}

/**
 * Initializes power saving mode from IRQ.
 *
 */
static void dc_toggle(void)
{
	SMPS_OFF();
	DMUX_STOP();
}

/**
 * Character received callback.
 *
 */
void uart_rx_cb(uint8_t id)
{
	ctx.uart = 1;
}

/**
 * Parse a command.
 */ 
static void parse_command(void)
{
	static char buffer[15] = {0};
	static unsigned i = 0;
	char *bp;

	ctx.input = 1;
	
	while (i < sizeof(buffer) - 1) {
		if (!uart_read(0, (uint8_t *)buffer + i, 1))
			break;
		uart_write(0, (uint8_t *)buffer + i, 1);
		i++;
	}
	ctx.uart = 0;

	if (buffer[i - 1] == '\r' || buffer[i - 1] == '\n') {
		if ((bp = strstr(buffer, "smps off"))) {
			SMPS_OFF();
			DMUX_STOP();
		} else if ((bp = strstr(buffer, "smps on"))) {
			SMPS_ON();
			DMUX_START();
		} else if ((bp = strstr(buffer, "smps dc"))) {
			ctx.duty_cycle = atoi(bp + 8);
			SMPS_SET_DC(ctx.duty_cycle);
		} else if (strstr(buffer, "beep")) {
			ctx.beep = 1;
		} else if (strstr(buffer, "reset")) {
			while (1);
		} else if ((bp = strstr(buffer, "set"))) {
			bp[6] = 0;	
			bp[9] = 0;
			bp[12] = 0;
			ctx.time.hh = atoi(bp + 4);
			ctx.time.mm = atoi(bp + 7);
			ctx.time.ss = atoi(bp + 10);
		} else if ((bp = strstr(buffer, "alarm"))) {
			bp[8] = 0;	
			bp[11] = 0;
			bp[14] = 0;
			ctx.alarm.hh = atoi(bp + 6);
			ctx.alarm.mm = atoi(bp + 9);
			ctx.alarm.ss = atoi(bp + 12);
			log_debug("Alarm %02d:%02d:%02d", ctx.alarm.hh, ctx.alarm.mm, ctx.alarm.ss);
		} else if ((bp = strstr(buffer, "dbg on"))) {
			if (strstr(bp, "dcf")) 
				ctx.dcf_debug = 1;
			else
				ctx.debug =1;
		} else if ((bp = strstr(buffer, "dbg off"))) {
			if (strstr(bp, "dcf")) 
				ctx.dcf_debug = 0;
			else
				ctx.debug = 0;
		} else if ((bp = strstr(buffer, "dcf"))) {
			log_info("Sync cnt %d, last sync %02d/%02d/%02d %02d:%02d:%02d", \
					 ctx.dcf_sync_cnt, 
					 dcf_time.day, dcf_time.month, dcf_time.year, 
					 dcf_time.hour, dcf_time.minute);
		}

		i = 0;
		ctx.input = 0;
	} else if (i == sizeof(buffer) - 1) {
		for (unsigned j = i; j > 0; j--) {
			buffer[j - 1] = buffer[j];
		}
		i--;
	}

	buffer[i] = 0;
}

static void check_buttons(void)
{
	if (BTN_HH == 0) {
		// debounce
		_delay_ms(20);
		if (BTN_HH == 0) {
			ctx.time.hh = (ctx.time.hh < 23) ? ctx.time.hh + 1 : 0;
		}
	}
	if (BTN_MM == 0) {
		// debounce
		_delay_ms(20);
		if (BTN_MM == 0) {
			ctx.time.mm = (ctx.time.mm < 59) ? ctx.time.mm + 1 : 0;
		}
	}
}

/**
 * Update display.
 * 
 * This function calculates new digit values and updates
 * SMPS DC according to light conditions.
 *
 */
static void refresh(void)
{
	ctx.digit[0] = ctx.time.hh / 10;
	ctx.digit[1] = ctx.time.hh % 10;
	ctx.digit[2] = ctx.time.mm / 10;
	ctx.digit[3] = ctx.time.mm % 10;

	ctx.adc_light = adc_read(ADC_VL, NULL);

#if ADAPTIVE_DC == 1
	ctx.duty_cycle = SMPS_PWM_DC;
	for (int i = 0; i < sizeof(dc_light_map)/sizeof(dc_light_map[0]); i++) {
		if (ctx.adc_light > dc_light_map[i][0])
			ctx.duty_cycle = dc_light_map[i][1];
	}
	SMPS_SET_DC(ctx.duty_cycle);
#endif
}

/**
 * Main loop when MCU is active.
 *
 */
__attribute__((OS_main))
int main(void)
{
	hw_init();

	uart_init(UART0, UART_BAUD_SELECT(UART_BAUD_RATE), uart_rx_cb, NULL);
	log_init();

	sei();
	
	log_info("Init done!");

	while (1) {
		adc_init(ADC_INT, ADC_PRE128, 0);
		
		SMPS_ON();
		DMUX_START();

		wdt_enable(WDTO_2S);
		set_sleep_mode(SLEEP_MODE_IDLE);

		while (bit_is_clear(ACSR, ACO)) {
			if (ctx.tick) {
				ctx.tick = 0;
				refresh();
				if (ctx.debug && !ctx.input) {
					ctx.adc_hv = adc_read(ADC_HV, NULL);
					uint32_t hv = HV_FROM_ADC(ctx.adc_hv);
					log_debug("HV:%ld Light:%d DC:%d", hv, ctx.adc_light, ctx.duty_cycle);
					log_debug("Local time: %02d:%02d:%02d", ctx.time.hh, ctx.time.mm, ctx.time.ss);
				}
			}

			if (ctx.uart) {
				parse_command();
			}

			if (ctx.beep) {
				ctx.beep = 0;
				PAD_HIGH(&buzzer_pad);
				_delay_ms(20);
				PAD_LOW(&buzzer_pad);
			}

			if (ctx.poll) {
				ctx.poll = 0;
				check_buttons();
			}

			if (ctx.dcf_sync) {
				ctx.dcf_sync = 0;
				ctx.time.hh = dcf_time.hour;
				ctx.time.mm = dcf_time.minute;
				ctx.time.ss = 0;
			}

			if (ctx.dcf_irq && ctx.dcf_debug && !ctx.input) {
				ctx.dcf_irq = 0;
				log_debug("DCF state: %d", dcf_state);
			}

			sleep_mode();
			wdt_reset();
		}

		wdt_disable();

		adc_deinit();
		uart_deinit(UART0);

		PORTB &= 0xE0;
		PORTC &= 0xF0;
		PORTD &= 0x9C;

		set_sleep_mode(SLEEP_MODE_PWR_SAVE);

		while (bit_is_set(ACSR, ACO)) {
			ACSR |= _BV(ACD);
			_delay_us(50);
			sleep_mode();
			ACSR &= ~_BV(ACD);
		}
		
		uart_init(UART0, UART_BAUD_SELECT(UART_BAUD_RATE), uart_rx_cb, NULL);
	}
}

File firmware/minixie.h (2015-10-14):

/**
 * Minixie - a simple nixie tube clock.
 * Copyright (C) 2012-2014, Wojciech Bober
 *
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
 */
#ifndef _MINIXIE_H_
#define _MINIXIE_H_

#include "logger.h"

#ifndef F_CPU
#define F_CPU 8000000UL
#endif

#ifndef LOG_SEVERITY
#define LOG_SEVERITY LOG_DEBUG
#endif

#ifndef UART_QUEUE_SIZE
#define UART_QUEUE_SIZE 50
#endif

#ifndef UART_BAUD_RATE
#define UART_BAUD_RATE  19200
#endif

#ifndef ADAPTIVE_DC
#define ADAPTIVE_DC     0
#endif

// OC1A = PB1
// OC1B = PB2
// SMPS default params
#define SMPS_PWM_FREQ   50
#define SMPS_PWM_PERIOD (F_CPU/SMPS_PWM_FREQ/1000)
#define SMPS_PWM_DC     80 // in %
#define SMPS_ON()       do { TCCR1B |= _BV(CS10); TCCR1A |= _BV(COM1A1); } while (0) //no prescaling
#define SMPS_OFF()      do { TCCR1B &= ~(_BV(CS21) | _BV(CS11) | _BV(CS10)); TCCR1A &= ~_BV(COM1A1); } while (0)
#define SMPS_SET_DC(dc) (OCR1A = (dc*SMPS_PWM_PERIOD)/100)

// buttons pins
#define BTN_HH          (PIND & _BV(PD4))
#define BTN_MM          (PIND & _BV(PD3))

// ADC macros
#define ADC_HV          4
#define ADC_VL          5

#define HV_R6           268000UL        // in ohm
#define HV_R7           3240UL          // in ohm
#define HV_FROM_ADC(n)  ({uint32_t _r = ADC_MV(n)*(HV_R6+HV_R7)/HV_R7/1000; _r;})

#define DMUX_START()    (TCCR0 |= _BV(CS00))
#define DMUX_STOP()     (TCCR0 &= ~_BV(CS00))

#define PWM_TOP         50

// a structure to hold time
typedef struct {
	int hh;
	int mm;
	int ss;
} clock_t;

// a simple pad type definition
typedef struct {
	volatile uint8_t *port;
	int pin;
} pad_t;

// a convenience macro to define a pad
#define PAD(_port, _pin) {.port = _port, .pin = _pin}

// convenience macros to set a pad state
#define PAD_HIGH(_pad)   *((_pad)->port) |= (1 << (_pad)->pin)
#define PAD_LOW(_pad)    *((_pad)->port) &= ~(1 << (_pad)->pin)
#define PAD_TOGGLE(_pad) *((_pad)->port) ^= (1 << (_pad)->pin)

#define INLINE inline

#endif

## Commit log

2014-12-21 Replaced backup capacitor with a CR1220 battery holder.
    [NixieClock.brd, NixieClock.sch]
2015-10-10 Enabled minutes button
2015-10-10 Added screenshot of fuse bits settings
2016-08-23 Changed MOSFET from IRF710 to IRF740. Added part number for inductor
    [NixieClock.brd, NixieClock.sch]
2016-08-23 Added part number for photoresistor
    [NixieClock.brd, NixieClock.sch]

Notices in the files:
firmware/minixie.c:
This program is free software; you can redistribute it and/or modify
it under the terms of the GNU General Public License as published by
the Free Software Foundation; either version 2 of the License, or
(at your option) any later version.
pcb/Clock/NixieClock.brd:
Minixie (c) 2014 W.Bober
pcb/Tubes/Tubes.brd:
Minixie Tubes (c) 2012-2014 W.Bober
